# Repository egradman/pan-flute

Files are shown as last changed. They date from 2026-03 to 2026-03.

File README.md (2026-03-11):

# Pan Flute

This was vibe-coded by me and my son Dash. It was a silly and fun idea, but one I would have discarded as "too complicated" until code became cheap and easy.

The key insight: **the same agentic coding tools we use to summon code into existence can be used to summon physical objects into existence.** OpenSCAD is a programmatic CAD tool — geometry defined as code — which makes it a perfect target for AI-assisted generation. We used Claude Code to write Python that generates OpenSCAD, turning a JSON list of musical notes into a 3D-printable object with acoustically correct tube lengths, engraved labels, and structural supports. No manual CAD work required beyond the initial mouthpiece design.

A parametric, 3D-printable two-tone pan flute generator. Define a song as JSON note pairs, and the toolchain produces a ready-to-print STL with acoustically tuned bore lengths, an engraved nameplate, and note labels on every tube.

## How It Works

Each column of the flute has **two tubes** that share a single mouthpiece. The airway is designed to route your breath into both tubes simultaneously, producing a **chord**. The tube lengths are calculated from the target frequencies using quarter-wave resonance, so the flute is (in theory) in tune right off the print bed.

### The Base Geometry

The sounding board / mouthpiece was modelled in **Rhino3D** and exported as STL. This is the part that's hard to parametrize — the airway geometry, blow edge, and air escape holes all need to be just right for the flute to actually produce sound. Two base variants exist:

| File | Description |
|---|---|
| `box-base.stl` | Dual rectangular-bore base with integrated air escape holes (7×7.75mm bores) |
| `pan_tube.stl` | **(deprecated)** Earlier single round-bore attempt — kept for reference |

Everything above the base — the tube extensions that determine pitch — is generated parametrically.

### The Pipeline

```
song.json ──→ Python ──→ OpenSCAD (.scad) ──→ STL
                              ↑
                         base STL from Rhino
```

Python reads your song file, calculates the extension length each tube needs to hit its target frequency, and writes out OpenSCAD code that imports the Rhino base and adds the right amount of tube on top.

## Song Format (JSON)

A song is a JSON array of note pairs. Each pair becomes one column on the flute:

```json
[
  ["C6", "E6"],
  ["G5", "B5"],
  ["E5", "G#5"],
  ["A5", "C#6"],
  ["B5", "D#6"],
  ["Bb5", "D6"],
  ["A5", "C#6"]
]
```

Each element is a two-element array: `[note_A, note_B]`. The two notes in a pair sound simultaneously as a chord when you blow into that column.

**Note name format:** `<letter><accidental?><octave>`

- **Letter:** `A` through `G`
- **Accidental (optional):** `#` (sharp) or `b` (flat)
- **Octave:** integer (pan flutes typically live in the `5`–`7` range)

Examples: `C6`, `F#5`, `Bb4`, `G#7`

See `mario.json` for a 7-column Super Mario Bros. theme, or `notes.json` for a simple diatonic scale.

## Usage

### Box-base variant (recommended)

```bash
# Generates flute.scad and renders in one step
python3 generate_flute.py mario.json MARIO
openscad -o mario.stl flute.scad
```

### Pan-tube variant (deprecated)

```bash
# 1. Generate the notes include file
python3 generate_notes.py mario.json

# 2. Render the STL (nameplate text is configurable)
openscad -D 'nameplate_text="MARIO"' -o mario.stl pan_flute.scad
```

## The Acoustic Math

Tube lengths are calculated using quarter-wave resonance for a closed-open pipe:

```
extension = speed_of_sound / (4 × freq) − end_correction − base_resonating_length
```

Where:
- **Speed of sound** = 343,000 mm/s (at ~20°C)
- **End correction** = `0.82 × bore_diameter` — accounts for the antinode extending slightly past the open end
- **Base resonating length** — the bore length already present in the imported STL (19.77mm for pan-tube, 7mm for box-base)

The `0.82` end-correction factor is empirical. If your prints are consistently sharp or flat, this is the knob to turn.

## Project Structure

```
├── pan_tube.stl          # Rhino3D base — round bore sounding board
├── box-base.stl          # Rhino3D base — rectangular dual-bore
├── pan_flute.scad        # Parametric OpenSCAD model (pan-tube variant)
├── generate_notes.py     # JSON → notes.scad (frequency arrays for pan_flute.scad)
├── generate_flute.py     # JSON → flute.scad (self-contained box-base variant)
├── notes.scad            # Generated include file (frequencies + note names)
├── flute.scad            # Generated OpenSCAD (box-base variant)
├── mario.json            # Example song: Super Mario Bros. theme
└── notes.json            # Example song: C major diatonic scale
```

## Tweaking

Key constants to adjust if things don't sound right:

| Constant | Pan-tube | Box-base | What it does |
|---|---|---|---|
| `end_correction_factor` | 0.82 | 0.82 | Raise to sharpen, lower to flatten |
| `tube_id` / `BORE_W` | 7.022mm | 7.0mm | Bore diameter — affects end correction |
| `obj_resonating_length` / `BASE_RESONATING` | 19.768mm | 7.0mm | Must match your actual STL |
| `speed_of_sound` | 343000 | 343000 | Varies with temperature (~+0.6 m/s per °C) |

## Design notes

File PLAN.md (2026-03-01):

# Pan Flute Website Plan

## Overview

A web app where users design custom pan flutes using a piano-roll beat sequencer, preview them in 3D, and pay $2.99 to download the STL or $19.99 to have one printed and mailed to them.

## Architecture

```
┌─────────────────────────────┐
│   Cloudflare Pages          │
│   Next.js (static + edge)   │
│                             │
│  ┌───────────────────────┐  │
│  │  Piano Roll Editor    │  │
│  │  Web Audio Preview    │  │
│  │  Three.js 3D Preview  │  │
│  └───────────────────────┘  │
│                             │
│  ┌───────────────────────┐  │
│  │  CF Workers (API)     │  │
│  │  - POST /checkout     │  │
│  │  - POST /webhook      │  │
│  │  - GET  /download/:id │  │
│  └───────────────────────┘  │
└────────────┬────────────────┘
             │
             │ After payment confirmed
             ▼
┌─────────────────────────────┐
│   Fly.io Docker Runner      │
│                             │
│   Python + OpenSCAD         │
│   - Receives note JSON      │
│   - Runs generate_notes.py  │
│   - Runs openscad render    │
│   - Returns STL binary      │
└─────────────────────────────┘
```

## Stack

| Layer | Technology |
|---|---|
| Frontend | Next.js 14+ (App Router), React, TypeScript |
| Styling | Tailwind CSS |
| 3D Preview | Three.js (via @react-three/fiber) |
| Audio | Web Audio API (oscillators) |
| Hosting (frontend + API) | Cloudflare Pages + Workers |
| STL Rendering | Fly.io Docker container (Python + OpenSCAD) |
| Payments | Stripe Checkout (redirect flow) |
| Storage | Cloudflare R2 (temporary STL storage) |
| Database | Cloudflare KV (order tracking, download tokens) |

## Feature Spec

### 1. Piano Roll Sequencer

- **Grid layout**: Y-axis is pitch (C4–C7, 3 octaves = 36 semitones), X-axis is columns (time slots)
- **Interactions**:
  - Click a cell to toggle a note on/off
  - Each column must have exactly 2 notes selected. If the user selects only 1 note, it is duplicated to fill both slots (same note in upper and lower row)
  - If a user clicks a 3rd note in a column, the oldest selection in that column is deselected
  - Buttons to add/remove columns (min 2, max ~16 for printability)
- **Visual design**:
  - Piano key labels on left edge (white/black key coloring)
  - Active notes highlighted
  - Column numbers along the top
- **Nameplate**: text input field below the grid for custom engraved text

### 2. Audio Preview

- Web Audio API with simple sine/triangle oscillators
- "Play" button steps through columns left-to-right
  - Each column plays its 2 notes simultaneously as a short tone (~200ms)
  - Small gap between columns (~50ms)
- Tempo slider optional (nice-to-have)

### 3. 3D Preview (Client-Side)

- Three.js scene rendered below the sequencer using @react-three/fiber
- Build an approximate flute model directly from note data:
  - For each column, compute tube extension lengths using the same formula as `pan_flute.scad`:
    ```
    extension = (343000 / (4 * freq)) - end_correction - obj_resonating_length
    ```
  - Render cylinders for each tube (upper + lower row)
  - Render gap fills and sounding boards as simplified geometry
- OrbitControls for rotate/zoom
- Updates live as user edits the grid
- Disclaimer: "Preview is approximate. Final STL may differ slightly."

### 4. Checkout Flow

1. User finishes design, sees two options:
   - **"Download STL — $2.99"** — digital download of the 3D-printable file
   - **"We'll print & mail it — $19.99"** — we 3D-print the flute and ship it to them
2. Frontend sends note data + nameplate text + selected tier to `POST /api/checkout`
3. Worker creates a Stripe Checkout Session:
   - Product: "Custom Pan Flute STL" ($2.99) or "Custom Pan Flute — Printed & Shipped" ($19.99)
   - For the physical tier, Stripe Checkout collects shipping address
   - Metadata: serialized note JSON + nameplate text + tier
   - success_url: `/order/{session_id}`
   - cancel_url: `/` (back to editor, state preserved in URL hash)
4. User redirected to Stripe Checkout
5. Stripe redirects back to success_url after payment

### 5. STL Generation + Download (Digital Tier — $2.99)

1. Stripe fires `checkout.session.completed` webhook → `POST /api/webhook`
2. Worker verifies webhook signature, extracts note data from metadata
3. Worker calls Fly.io renderer: `POST https://flute-renderer.fly.dev/render`
   - Body: `{ notes: [["C7","E7"], ...], nameplate: "My Flute" }`
4. Fly.io container:
   - Writes JSON to temp file
   - Runs `python3 generate_notes.py input.json` → `notes.scad`
   - Patches nameplate text in `pan_flute.scad` (or pass as OpenSCAD variable via `-D`)
   - Runs `openscad -o output.stl pan_flute.scad`
   - Returns STL binary in response
5. Worker stores STL in Cloudflare R2 with a unique key
6. Worker stores download token in KV: `{session_id} → {r2_key, email, expires}`
7. When user hits `/order/{session_id}`:
   - Worker looks up token in KV
   - Serves STL from R2 as file download
   - Downloads expire after 7 days (link emailed to buyer)

### 6. Physical Order (Printed & Shipped Tier — $19.99)

- Same Stripe Checkout flow but with shipping address collection enabled
- Stripe includes the note JSON + nameplate text in the session metadata
- No custom backend fulfillment — Stripe emails you the order. You pull the JSON from the Stripe dashboard, render the STL locally, print it, and ship it.
- Future: add admin dashboard and order tracking if volume warrants it

### 7. Email Delivery

- **Digital tier**: download link email sent when STL is ready (via Resend, Postmark, or Cloudflare Email Workers)
- **Physical tier**: Stripe sends payment receipt to customer; you handle fulfillment manually

## Fly.io Renderer Service

### Dockerfile

```dockerfile
FROM ubuntu:24.04

RUN apt-get update && apt-get install -y \
    openscad python3 \
    && rm -rf /var/lib/apt/lists/*

WORKDIR /app
COPY generate_notes.py pan_flute.scad pan_tube.stl ./

# Minimal HTTP server (Python or Go)
COPY server.py ./
CMD ["python3", "server.py"]
```

### API

- `POST /render` — accepts JSON body, returns STL binary
- Internal only (authenticated via shared secret between CF Worker and Fly.io)
- Timeout: 120s (OpenSCAD can be slow on complex models)
- Concurrency: 1 render at a time per instance, scale horizontally via Fly.io machines

### Pipeline Changes Needed

1. **Nameplate customization**: Pass nameplate text as an OpenSCAD variable: `openscad -D 'nameplate_text="USER TEXT"' -o out.stl pan_flute.scad`
   - Modify `pan_flute.scad` to use a variable instead of hardcoded "MARIO"
2. **Single-note columns**: When only 1 note is selected, `generate_notes.py` should output the same frequency for both upper and lower row (already handled by frontend duplication, but validate server-side too)

## Pages / Routes

| Route | Description |
|---|---|
| `/` | Main page: piano roll editor + 3D preview + checkout buttons |
| `/order/[sessionId]` | Order page: STL download (digital) or order status + tracking (physical) |
| `/api/checkout` | CF Worker: creates Stripe session (digital or physical tier) |
| `/api/webhook` | CF Worker: handles Stripe webhook, triggers render |
| `/api/download/[sessionId]` | CF Worker: serves STL from R2 |

## Data Flow Summary

```
User designs flute in piano roll
         │
         ▼
Note data serialized as JSON + nameplate text
         │
         ├─── "Download STL — $2.99" ──── or ──── "Print & Ship — $19.99" ───┐
         ▼                                                                    ▼
POST /api/checkout (digital)                          POST /api/checkout (physical, +shipping)
         │                                                                    │
         ▼                                                                    ▼
Stripe Checkout ($2.99)                               Stripe Checkout ($19.99 + address)
         │                                                                    │
         └──────────────────┬─────────────────────────────────────────────────┘
                            ▼
              Webhook → Fly.io renders STL → R2
                            │
              ┌─────────────┴─────────────┐
              ▼                           ▼
     /order/{id}: download         /order/{id}: status tracker
     + email with link             + fulfillment queue → you print & ship
                                   + email with tracking when shipped
```

## Implementation Phases

### Phase 1: Piano Roll UI
- Next.js project scaffold with Tailwind
- Piano roll grid component (click to toggle, column add/remove)
- Note data model (JSON serialization matching pipeline format)
- Nameplate text input

### Phase 2: Audio + 3D Preview
- Web Audio playback of note sequence
- Three.js approximate flute model from note data
- Live reactivity (edit grid → model updates)

### Phase 3: Fly.io Renderer
- Dockerfile with OpenSCAD + Python
- HTTP server accepting render requests
- Parameterize `pan_flute.scad` for nameplate text
- Deploy to Fly.io, test end-to-end

### Phase 4: Stripe + Cloudflare Integration (Digital Tier)
- Stripe Checkout integration (CF Worker)
- Webhook handler + render job dispatch
- R2 storage for STL files
- KV for download tokens
- Order page + file serving

### Phase 5: Physical Tier
- Add $19.99 "Print & Ship" button alongside digital download
- Stripe Checkout with shipping address collection
- Note JSON + nameplate stored in Stripe session metadata (you handle fulfillment from Stripe dashboard)

### Phase 6: Polish
- Loading states and progress indication during render
- Error handling (render failures, payment issues)
- Mobile-responsive piano roll
- Email delivery (download links + order confirmations + shipping notifications)
- Rate limiting / abuse prevention
- Landing page copy and design

## Open Questions / Risks

1. **OpenSCAD render time**: Complex flutes (16 columns) may take 60-120s. Need a good loading UX (progress bar, email fallback).
2. **Fly.io cold starts**: First render after idle may be slow. Consider keeping a minimum of 1 machine alive or using Fly Machines API for on-demand spin-up.
3. **Tube length limits**: Very low notes (C4) produce long tubes. May need to warn users or cap the low range if tubes exceed printable dimensions.
4. **Mobile UX**: Piano roll grids are tricky on small screens. May need a simplified mobile interface or landscape-only mode.

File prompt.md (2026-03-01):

we're making an OpenSCAD system to create custom pan flutes from two-tone note sequences.  A pan flute is consists of columns, which correspond to the X axis, and
  exactly two rows, which correspond to notes that will sound simultaneously (chords).  a single "tube" consists of an imported OBJ file (the complicated sounding
  board) and a "capped tube extension" which resonates in the required frequency.  there will be Nx2 tubes.  For a single chord, the two tube assemblies point in
  opposite directions (one points "up" and one points "down").  we need constants for the tube inner diameter, tube outer diameter, tube center spacing, displacement
  to where the tube extension starts.  the tube sounding OBJ is in this directory.  The input to the script will be a sequence of note pairs (JSON) of unbounded
  length.

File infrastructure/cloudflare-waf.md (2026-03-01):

# Cloudflare WAF Rules — Pan Flute Production

Recommended Cloudflare WAF configuration for the pan flute storefront
deployed on Cloudflare Pages.

---

## 1. Rate Limiting Rules (WAF Custom Rules)

These operate at the Cloudflare edge, **before** the request reaches the
Workers runtime, so they shed abusive traffic at no compute cost.

### Checkout endpoint

| Field | Value |
|---|---|
| Rule name | `rate-limit-checkout` |
| Match | `URI Path equals /api/checkout` AND `Method equals POST` |
| Rate | 10 requests per 60 seconds |
| Counting expression | Per IP (`ip.src`) |
| Action | Block (429) |
| Duration | 60 seconds |

### Webhook endpoint

Stripe retries on failure, so avoid overly aggressive limits. The
endpoint already validates the Stripe signature; the WAF rule is a
defence-in-depth measure.

| Field | Value |
|---|---|
| Rule name | `rate-limit-webhook` |
| Match | `URI Path equals /api/webhook` AND `Method equals POST` |
| Rate | 60 requests per 60 seconds |
| Counting expression | Per IP (`ip.src`) |
| Action | Block (429) |
| Duration | 60 seconds |

### Global API catch-all

| Field | Value |
|---|---|
| Rule name | `rate-limit-api-global` |
| Match | `URI Path starts with /api/` |
| Rate | 100 requests per 60 seconds |
| Counting expression | Per IP (`ip.src`) |
| Action | Challenge (Managed Challenge) |
| Duration | 120 seconds |

---

## 2. Bot Protection

Cloudflare's **Bot Fight Mode** should be enabled (free tier) or
**Super Bot Fight Mode** (Pro+). Configure as follows:

- **Definitely automated** → Block
- **Likely automated** → Managed Challenge
- **Verified bots** (e.g., Googlebot) → Allow

Add a WAF custom rule to block requests with low bot scores on the
checkout endpoint:

| Field | Value |
|---|---|
| Rule name | `bot-block-checkout` |
| Match | `URI Path equals /api/checkout` AND `cf.bot_management.score lt 30` |
| Action | Block |

> Note: `cf.bot_management.score` requires the Enterprise plan.  On
> Pro/Business, use **Super Bot Fight Mode** toggles instead.

---

## 3. IP Reputation Filtering

Enable the built-in Cloudflare **IP Access Rules**:

- Block traffic from **Tor exit nodes** if your use case doesn't require
  Tor support (Security > WAF > Tools > IP Access Rules).
- Consider blocking known-bad ASNs that appear in your abuse logs.

For an additional layer, add a WAF rule:

| Field | Value |
|---|---|
| Rule name | `block-high-threat-score` |
| Match | `cf.threat_score gt 50` |
| Action | Managed Challenge |

---

## 4. Additional Hardening

### Stripe webhook origin restriction

Stripe publishes its webhook source IP ranges. Create an IP Access rule
or WAF rule that only allows `/api/webhook` from those ranges:

```
URI Path equals /api/webhook
AND ip.src not in {list:stripe-webhook-ips}
→ Block
```

Maintain the IP list as a Cloudflare List
(Security > WAF > Tools > Lists) and update it periodically from
https://stripe.com/docs/ips.

### HTTPS-only

Ensure the **Always Use HTTPS** setting is enabled under SSL/TLS > Edge
Certificates.  This is on by default for Cloudflare Pages custom
domains.

### Headers

Add the following security response headers via a Cloudflare Transform
Rule (or `_headers` file in Pages):

```
X-Content-Type-Options: nosniff
X-Frame-Options: DENY
Referrer-Policy: strict-origin-when-cross-origin
Permissions-Policy: camera=(), microphone=(), geolocation=()
```

---

## 5. Monitoring

- Enable **Security Events** notifications (email or webhook) so you are
  alerted when rate-limit or bot rules fire at an unusual rate.
- Review the **Security > Analytics** dashboard weekly to tune
  thresholds.

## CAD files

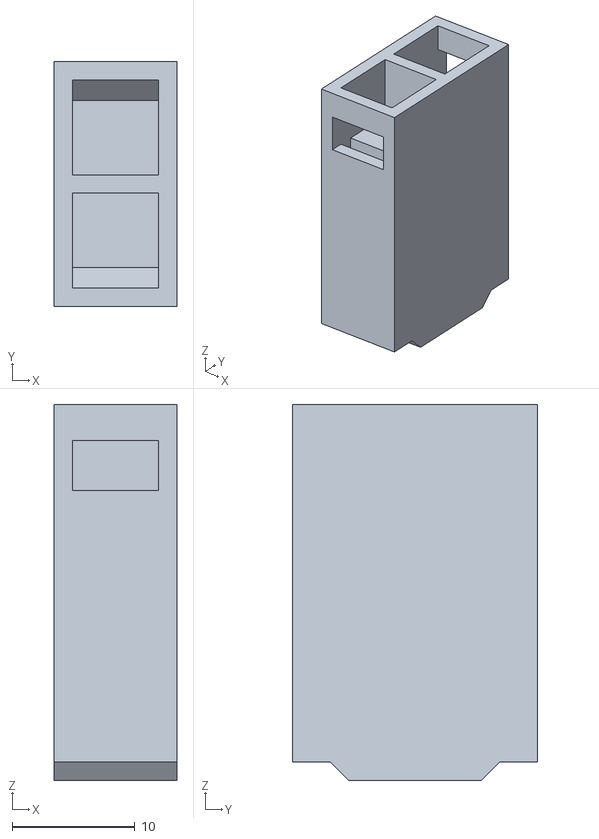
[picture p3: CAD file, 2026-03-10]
box-base.stl
10.0 x 20.0 x 30.7

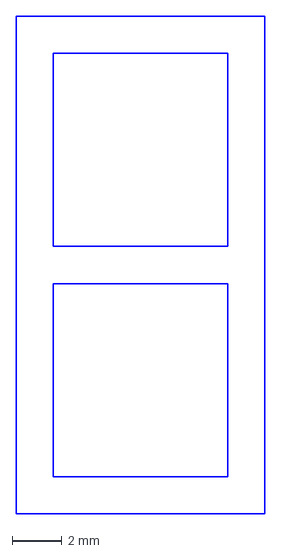
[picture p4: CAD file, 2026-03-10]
profile.dxf
10.0 x 20.0 mm

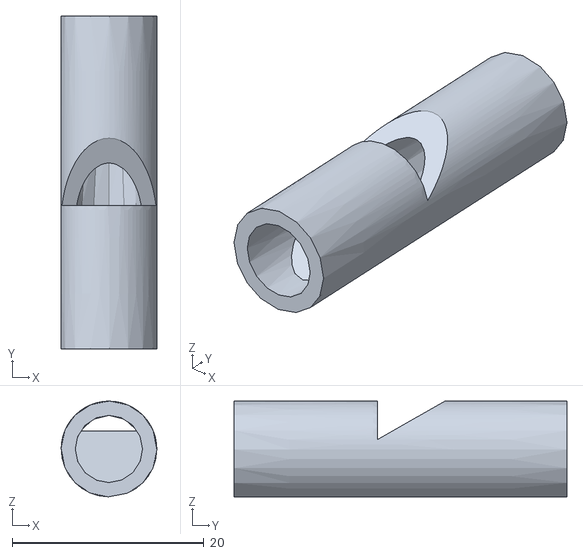
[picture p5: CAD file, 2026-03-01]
pan_tube.stl
9.99 x 34.8 x 9.99

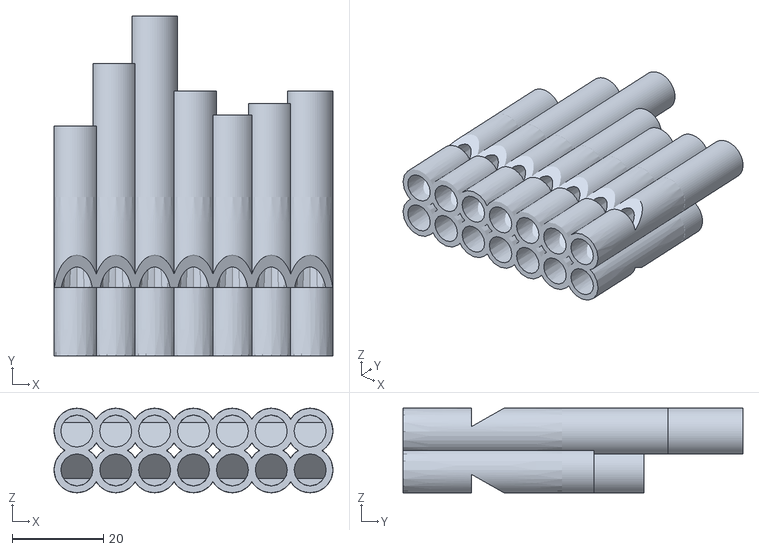
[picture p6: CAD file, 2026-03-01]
mario.stl
61.0 x 74.3 x 18.5

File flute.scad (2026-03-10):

// Box-base pan flute — generated by generate_flute.py
// Do not edit by hand

difference() {
  union() {
    // Column 0: C6 (1046.5 Hz) / E6 (1318.5 Hz)
    // ext_a=68.91mm  ext_b=52.00mm
    translate([0.0, 0, 0]) {
      import("box-base.stl", convexity=10);
      difference() {
        // Tube A outer — C6
        translate([-5.0, -10.0, 0])
          cube([10.0, 10.0, 70.4078]);
        translate([-3.5, -8.5, -0.01])
          cube([7.0, 7.75, 68.9178]);
      }
      difference() {
        // Tube B outer — E6
        translate([-5.0, 0, 0])
          cube([10.0, 10.0, 53.5037]);
        translate([-3.5, 0.75, -0.01])
          cube([7.0, 7.75, 52.0137]);
      }
    }

    // Column 1: G5 (784.0 Hz) / B5 (987.8 Hz)
    // ext_a=96.34mm  ext_b=73.78mm
    translate([10.0, 0, 0]) {
      import("box-base.stl", convexity=10);
      difference() {
        // Tube A outer — G5
        translate([-5.0, -10.0, 0])
          cube([10.0, 10.0, 97.8444]);
        translate([-3.5, -8.5, -0.01])
          cube([7.0, 7.75, 96.3544]);
      }
      difference() {
        // Tube B outer — B5
        translate([-5.0, 0, 0])
          cube([10.0, 10.0, 75.2801]);
        translate([-3.5, 0.75, -0.01])
          cube([7.0, 7.75, 73.7901]);
      }
    }

    // Column 2: E5 (659.3 Hz) / G#5 (830.6 Hz)
    // ext_a=117.04mm  ext_b=90.21mm
    translate([20.0, 0, 0]) {
      import("box-base.stl", convexity=10);
      difference() {
        // Tube A outer — E5
        translate([-5.0, -10.0, 0])
          cube([10.0, 10.0, 118.5392]);
        translate([-3.5, -8.5, -0.01])
          cube([7.0, 7.75, 117.0492]);
      }
      difference() {
        // Tube B outer — G#5
        translate([-5.0, 0, 0])
          cube([10.0, 10.0, 91.7056]);
        translate([-3.5, 0.75, -0.01])
          cube([7.0, 7.75, 90.2156]);
      }
    }

    // Column 3: A5 (880.0 Hz) / C#6 (1108.7 Hz)
    // ext_a=84.41mm  ext_b=64.31mm
    translate([30.0, 0, 0]) {
      import("box-base.stl", convexity=10);
      difference() {
        // Tube A outer — A5
        translate([-5.0, -10.0, 0])
          cube([10.0, 10.0, 85.9113]);
        translate([-3.5, -8.5, -0.01])
          cube([7.0, 7.75, 84.4213]);
      }
      difference() {
        // Tube B outer — C#6
        translate([-5.0, 0, 0])
          cube([10.0, 10.0, 65.8088]);
        translate([-3.5, 0.75, -0.01])
          cube([7.0, 7.75, 64.3188]);
      }
    }

    // Column 4: B5 (987.8 Hz) / D#6 (1244.5 Hz)
    // ext_a=73.78mm  ext_b=55.87mm
    translate([40.0, 0, 0]) {
      import("box-base.stl", convexity=10);
      difference() {
        // Tube A outer — B5
        translate([-5.0, -10.0, 0])
          cube([10.0, 10.0, 75.2801]);
        translate([-3.5, -8.5, -0.01])
          cube([7.0, 7.75, 73.7901]);
      }
      difference() {
        // Tube B outer — D#6
        translate([-5.0, 0, 0])
          cube([10.0, 10.0, 57.3709]);
        translate([-3.5, 0.75, -0.01])
          cube([7.0, 7.75, 55.8809]);
      }
    }

    // Column 5: Bb5 (932.3 Hz) / D6 (1174.7 Hz)
    // ext_a=78.94mm  ext_b=59.97mm
    translate([50.0, 0, 0]) {
      import("box-base.stl", convexity=10);
      difference() {
        // Tube A outer — Bb5
        translate([-5.0, -10.0, 0])
          cube([10.0, 10.0, 80.4423]);
        translate([-3.5, -8.5, -0.01])
          cube([7.0, 7.75, 78.9523]);
      }
      difference() {
        // Tube B outer — D6
        translate([-5.0, 0, 0])
          cube([10.0, 10.0, 61.4680]);
        translate([-3.5, 0.75, -0.01])
          cube([7.0, 7.75, 59.9780]);
      }
    }

    // Column 6: A5 (880.0 Hz) / C#6 (1108.7 Hz)
    // ext_a=84.41mm  ext_b=64.31mm
    translate([60.0, 0, 0]) {
      import("box-base.stl", convexity=10);
      difference() {
        // Tube A outer — A5
        translate([-5.0, -10.0, 0])
          cube([10.0, 10.0, 85.9113]);
        translate([-3.5, -8.5, -0.01])
          cube([7.0, 7.75, 84.4213]);
      }
      difference() {
        // Tube B outer — C#6
        translate([-5.0, 0, 0])
          cube([10.0, 10.0, 65.8088]);
        translate([-3.5, 0.75, -0.01])
          cube([7.0, 7.75, 64.3188]);
      }
    }

  }

  // Nameplate: "MARIO"
  translate([30.0, -10.01, -19.689])
    rotate([-90, 0, 0])
      linear_extrude(height=0.52)
        mirror([0, 1, 0])
          text("MARIO", size=6, font="Liberation Sans:style=Bold", halign="center", valign="center");

  // Labels column 0: C6 / E6
  translate([0.0, -5.0, 70.41775787504537])
    mirror([0, 0, 1])
      linear_extrude(height=0.42000000000000004)
        rotate([0, 0, 180])
          text("C6", size=3, font="Liberation Sans:style=Bold", halign="center", valign="center");
  translate([0.0, 5.0, 53.513656897243315])
    mirror([0, 0, 1])
      linear_extrude(height=0.42000000000000004)
        rotate([0, 0, 180])
          text("E6", size=3, font="Liberation Sans:style=Bold", halign="center", valign="center");
  // Labels column 1: G5 / B5
  translate([10.0, -5.0, 97.85440905063936])
    mirror([0, 0, 1])
      linear_extrude(height=0.42000000000000004)
        rotate([0, 0, 180])
          text("G5", size=3, font="Liberation Sans:style=Bold", halign="center", valign="center");
  translate([10.0, 5.0, 75.29014136655454])
    mirror([0, 0, 1])
      linear_extrude(height=0.42000000000000004)
        rotate([0, 0, 180])
          text("B5", size=3, font="Liberation Sans:style=Bold", halign="center", valign="center");
  // Labels column 2: E5 / G#5
  translate([20.0, -5.0, 118.5491782012663])
    mirror([0, 0, 1])
      linear_extrude(height=0.42000000000000004)
        rotate([0, 0, 180])
          text("E5", size=3, font="Liberation Sans:style=Bold", halign="center", valign="center");
  translate([20.0, 5.0, 91.71559052652667])
    mirror([0, 0, 1])
      linear_extrude(height=0.42000000000000004)
        rotate([0, 0, 180])
          text("G#5", size=3, font="Liberation Sans:style=Bold", halign="center", valign="center");
  // Labels column 3: A5 / C#6
  translate([30.0, -5.0, 85.92131741140216])
    mirror([0, 0, 1])
      linear_extrude(height=0.42000000000000004)
        rotate([0, 0, 180])
          text("A5", size=3, font="Liberation Sans:style=Bold", halign="center", valign="center");
  translate([30.0, 5.0, 65.81884025587553])
    mirror([0, 0, 1])
      linear_extrude(height=0.42000000000000004)
        rotate([0, 0, 180])
          text("C#6", size=3, font="Liberation Sans:style=Bold", halign="center", valign="center");
  // Labels column 4: B5 / D#6
  translate([40.0, -5.0, 75.29014136655454])
    mirror([0, 0, 1])
      linear_extrude(height=0.42000000000000004)
        rotate([0, 0, 180])
          text("B5", size=3, font="Liberation Sans:style=Bold", halign="center", valign="center");
  translate([40.0, 5.0, 57.380870237250384])
    mirror([0, 0, 1])
      linear_extrude(height=0.42000000000000004)
        rotate([0, 0, 180])
          text("D#6", size=3, font="Liberation Sans:style=Bold", halign="center", valign="center");
  // Labels column 5: Bb5 / D6
  translate([50.0, -5.0, 80.452251857374])
    mirror([0, 0, 1])
      linear_extrude(height=0.42000000000000004)
        rotate([0, 0, 180])
          text("Bb5", size=3, font="Liberation Sans:style=Bold", halign="center", valign="center");
  translate([50.0, 5.0, 61.47804004900183])
    mirror([0, 0, 1])
      linear_extrude(height=0.42000000000000004)
        rotate([0, 0, 180])
          text("D6", size=3, font="Liberation Sans:style=Bold", halign="center", valign="center");
  // Labels column 6: A5 / C#6
  translate([60.0, -5.0, 85.92131741140216])
    mirror([0, 0, 1])
      linear_extrude(height=0.42000000000000004)
        rotate([0, 0, 180])
          text("A5", size=3, font="Liberation Sans:style=Bold", halign="center", valign="center");
  translate([60.0, 5.0, 65.81884025587553])
    mirror([0, 0, 1])
      linear_extrude(height=0.42000000000000004)
        rotate([0, 0, 180])
          text("C#6", size=3, font="Liberation Sans:style=Bold", halign="center", valign="center");

}

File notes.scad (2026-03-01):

// Generated by generate_notes.py — do not edit by hand
//
// Column 1: C7 (2093.00 Hz) / E7 (2637.02 Hz)
// Column 2: G6 (1567.98 Hz) / B6 (1975.53 Hz)
// Column 3: E6 (1318.51 Hz) / G#6 (1661.22 Hz)
// Column 4: A6 (1760.00 Hz) / C#7 (2217.46 Hz)
// Column 5: B6 (1975.53 Hz) / D#7 (2489.02 Hz)
// Column 6: Bb6 (1864.66 Hz) / D7 (2349.32 Hz)
// Column 7: A6 (1760.00 Hz) / C#7 (2217.46 Hz)

note_pairs = [
  [2093.005, 2637.020],
  [1567.982, 1975.533],
  [1318.510, 1661.219],
  [1760.000, 2217.461],
  [1975.533, 2489.016],
  [1864.655, 2349.318],
  [1760.000, 2217.461]
];

note_names = [
  ["C7", "E7"],
  ["G6", "B6"],
  ["E6", "G#6"],
  ["A6", "C#7"],
  ["B6", "D#7"],
  ["Bb6", "D7"],
  ["A6", "C#7"]
];

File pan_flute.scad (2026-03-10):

// Pan Flute — parametric two-tone pan flute generator
// Reads note_pairs from notes.scad (generated by generate_notes.py)

include <notes.scad>

// --- Parameters (overridable via -D on command line) ---
nameplate_text     = "";        // override with: openscad -D 'nameplate_text="YOUR TEXT"'

// --- Constants ---
tube_id            = 7.022;     // inner diameter (mm), from OBJ vertex analysis
tube_od            = 9.994;     // outer diameter (mm), from OBJ vertex analysis
wall_thickness     = (tube_od - tube_id) / 2;  // 1.486 mm
tube_spacing       = 8.5;       // center-to-center spacing (mm), more overlap for solid print
obj_total_length   = 34.766;    // OBJ Y extent (mm)
obj_resonating_length = 19.768; // resonating portion of OBJ (mm)
speed_of_sound     = 343000;    // mm/s (343 m/s at 20°C)
end_correction_factor = 0.82;   // empirical end-correction multiplier
row_offset         = tube_od / 2 - 0.75;  // Z offset between rows
fill_d             = 4;          // fill cylinder diameter (mm)
nameplate_depth    = 0.5;        // impression depth (mm)
nameplate_draft    = 0.2;        // taper per side for 3D printing (mm)

// --- Functions ---
function extension_length(freq) =
    speed_of_sound / (4 * freq) - end_correction_factor * tube_id - obj_resonating_length;

function tube_length(freq) =
    obj_total_length + max(0, extension_length(freq));

// --- Modules ---
module tube_assembly(freq) {
    // Sounding board from OBJ (Y = 0 to obj_total_length)
    import("pan_tube.stl", convexity=10);

    ext = extension_length(freq);
    if (ext > 0) {
        translate([0, obj_total_length, 0])
            rotate([-90, 0, 0])
                if (ext > wall_thickness) {
                    // Hollow extension with capped end
                    difference() {
                        cylinder(d=tube_od, h=ext, $fn=60);
                        cylinder(d=tube_id, h=ext - wall_thickness, $fn=60);
                    }
                } else {
                    // Extension too short for bore — solid plug
                    cylinder(d=tube_od, h=ext, $fn=60);
                }
    }
}

module chord_column(freq_up, freq_down) {
    // Top row — offset up in Z
    translate([0, 0, row_offset])
        tube_assembly(freq_up);
    // Bottom row — offset down in Z, rotated 180° around Y (long axis)
    translate([0, 0, -row_offset])
        rotate([0, 180, 0])
            tube_assembly(freq_down);
}

module row_fill() {
    // Solid bar spanning all columns, mouth to start of resonating bore
    // with bore holes preserved
    mouth_length = obj_total_length - obj_resonating_length;
    total_x = (len(note_pairs) - 1) * tube_spacing;
    difference() {
        translate([0, 0, -tube_od/2])
            cube([total_x, mouth_length, tube_od]);
        for (i = [0 : len(note_pairs) - 1])
            translate([i * tube_spacing, -1, 0])
                rotate([-90, 0, 0])
                    cylinder(d=tube_id, h=mouth_length + 2, $fn=60);
    }
}

module fill_gap(i) {
    min_len = min([
        tube_length(note_pairs[i][0]),
        tube_length(note_pairs[i][1]),
        tube_length(note_pairs[i+1][0]),
        tube_length(note_pairs[i+1][1])
    ]);
    translate([(i + 0.5) * tube_spacing, 0, 0])
        rotate([-90, 0, 0])
            cylinder(d=fill_d, h=min_len, $fn=30);
}

// General-purpose tapered impressed text — creates a solid at the origin for subtraction.
// Front face (surface) at Z=0, back face at Z=depth. Caller positions and rotates.
module impressed_text(str, size=4, depth=nameplate_depth, draft=nameplate_draft, font="Liberation Sans:style=Bold", halign="center", valign="center") {
    s = (size - 2*draft) / size;
    linear_extrude(height = depth + 0.01, scale = [s, s])
        text(str, size=size, font=font, halign=halign, valign=valign);
}

// Nameplate cut in global coordinates
module nameplate_cut() {
    mouth_length = obj_total_length - obj_resonating_length;
    np_width = (len(note_pairs) - 1) * tube_spacing;
    np_length = (mouth_length - tube_od) * 1.2;
    top_z = row_offset + tube_od / 2;

    // Flat pocket with tapered walls — bottom face centered, scales up to top
    translate([np_width/2, tube_od/2 + np_length/2, top_z - nameplate_depth])
        linear_extrude(height = nameplate_depth + 1, scale = [
            np_width / (np_width - 2*nameplate_draft),
            np_length / (np_length - 2*nameplate_draft)
        ])
            square([np_width - 2*nameplate_draft, np_length - 2*nameplate_draft], center=true);
}

// --- Main assembly ---
difference() {
    union() {
        for (i = [0 : len(note_pairs) - 1])
            translate([i * tube_spacing, 0, 0])
                chord_column(note_pairs[i][0], note_pairs[i][1]);

        // Fill interstitial gaps between adjacent columns
        for (i = [0 : len(note_pairs) - 2])
            fill_gap(i);

        // Fill between OBJ sounding boards on top and bottom rows
        translate([0, 0, row_offset])
            row_fill();
        translate([0, 0, -row_offset])
            row_fill();
    }

    // Nameplate impression — cuts both fill bar and tube tops flat
    nameplate_cut();

    // Nameplate text
    np_center_x = (len(note_pairs) - 1) * tube_spacing / 2;
    np_center_y = tube_od/2 + ((obj_total_length - obj_resonating_length) - tube_od) * 1.2 / 2;
    np_floor_z = row_offset + tube_od / 2 - nameplate_depth;
    translate([np_center_x, np_center_y, np_floor_z])
        mirror([0, 0, 1])
            impressed_text(nameplate_text, depth=0.4);

    // Note name labels impressed into each tube's end cap
    for (i = [0 : len(note_pairs) - 1]) {
        // Top row
        translate([i * tube_spacing, tube_length(note_pairs[i][0]) + 0.01, row_offset])
            rotate([90, 0, 0])
                mirror([1, 0, 0])
                    impressed_text(note_names[i][0], size=2.25, depth=0.4);
        // Bottom row
        translate([i * tube_spacing, tube_length(note_pairs[i][1]) + 0.01, -row_offset])
            rotate([90, 0, 0])
                mirror([1, 0, 0])
                    impressed_text(note_names[i][1], size=2.25, depth=0.4);
    }
}

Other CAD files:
pan_tube.obj

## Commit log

2026-03-01 Add pan flute generator with Super Mario theme melody
    Pan flute OpenSCAD project that generates 3D-printable pan flutes from
    note pairs. Includes Mario theme melody (C7-G6-E6-A6-B6-Bb6-A6) with
    fifths as harmony pairs.
    [mario.stl, notes.scad, pan_flute.scad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]
2026-03-01 Add pan flute designer web app with full e-commerce pipeline
    Complete Next.js web application for designing custom pan flutes:
    - Piano roll grid sequencer (C5-C7 range, 2-note columns)
    - Web Audio playback with triangle oscillators
    - Three.js 3D flute preview with live updates
    - Stripe Checkout integration (digital $2.99 + physical $19.99)
    - Fly.io Docker renderer service (OpenSCAD + Python)
    - Cloudflare Pages deployment config (R2 + KV + Workers)
    - Stripe webhook handler with HMAC-SHA256 verification
    - Order page with polling status and download serving
    - Email delivery via Resend API
    - KV-backed rate limiting on checkout endpoint
    - Mobile-responsive design with touch-friendly controls
    - Pa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
    [pan_flute.scad]
2026-03-01 Prepare for migration: update gitignore, add project plan
    - Add .dev.vars, credentials/, __pycache__, .wrangler/ to gitignore
    - Add PLAN.md with full project specification
    - Update mario.json with revised note pairs
    - Clean up stale dolt server state files
    [notes.scad]
2026-03-10 Selective merge from whoops: box-base generator + web copy
    Cherry-picked from whoops branch:
    - New box-base pan flute generator (flute.scad, generate_flute.py, box-base.stl)
    - Updated renderer to use new generator pipeline
    - Better web copy: "One-Song Pan Flutes", Dash's intro, friendlier steps
    - Kept Mario default and sweet spot indicator from main
    - Skipped Cloudflare infra changes (already correct on main)
    [box-base.stl, flute.scad, profile.dxf]
2026-03-10 Default nameplate to empty string instead of MARIO
    [pan_flute.scad]
2026-03-11 Update hero copy: clearer flute pitch and filament fund
